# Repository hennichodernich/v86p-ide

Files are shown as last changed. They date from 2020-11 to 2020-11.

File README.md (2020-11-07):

# V86P 8-Bit IDE Controller

This is a variant of the XT-IDE ISA controller by [Glitch Works](http://www.glitchwrks.com/xt-ide) for Victor V86P 8086 laptops and compatibles.

This board is intended to be used with a custom BIOS like the XT-IDE Universal BIOS.

This design is based on [rev 4 of the Glitch Works XT-IDE](https://github.com/glitchwrks/xt_ide/tree/rev_4) using the information obtained by [MattinX](https://knm.org.uk/blog/2017/05/v86p-expansion/).

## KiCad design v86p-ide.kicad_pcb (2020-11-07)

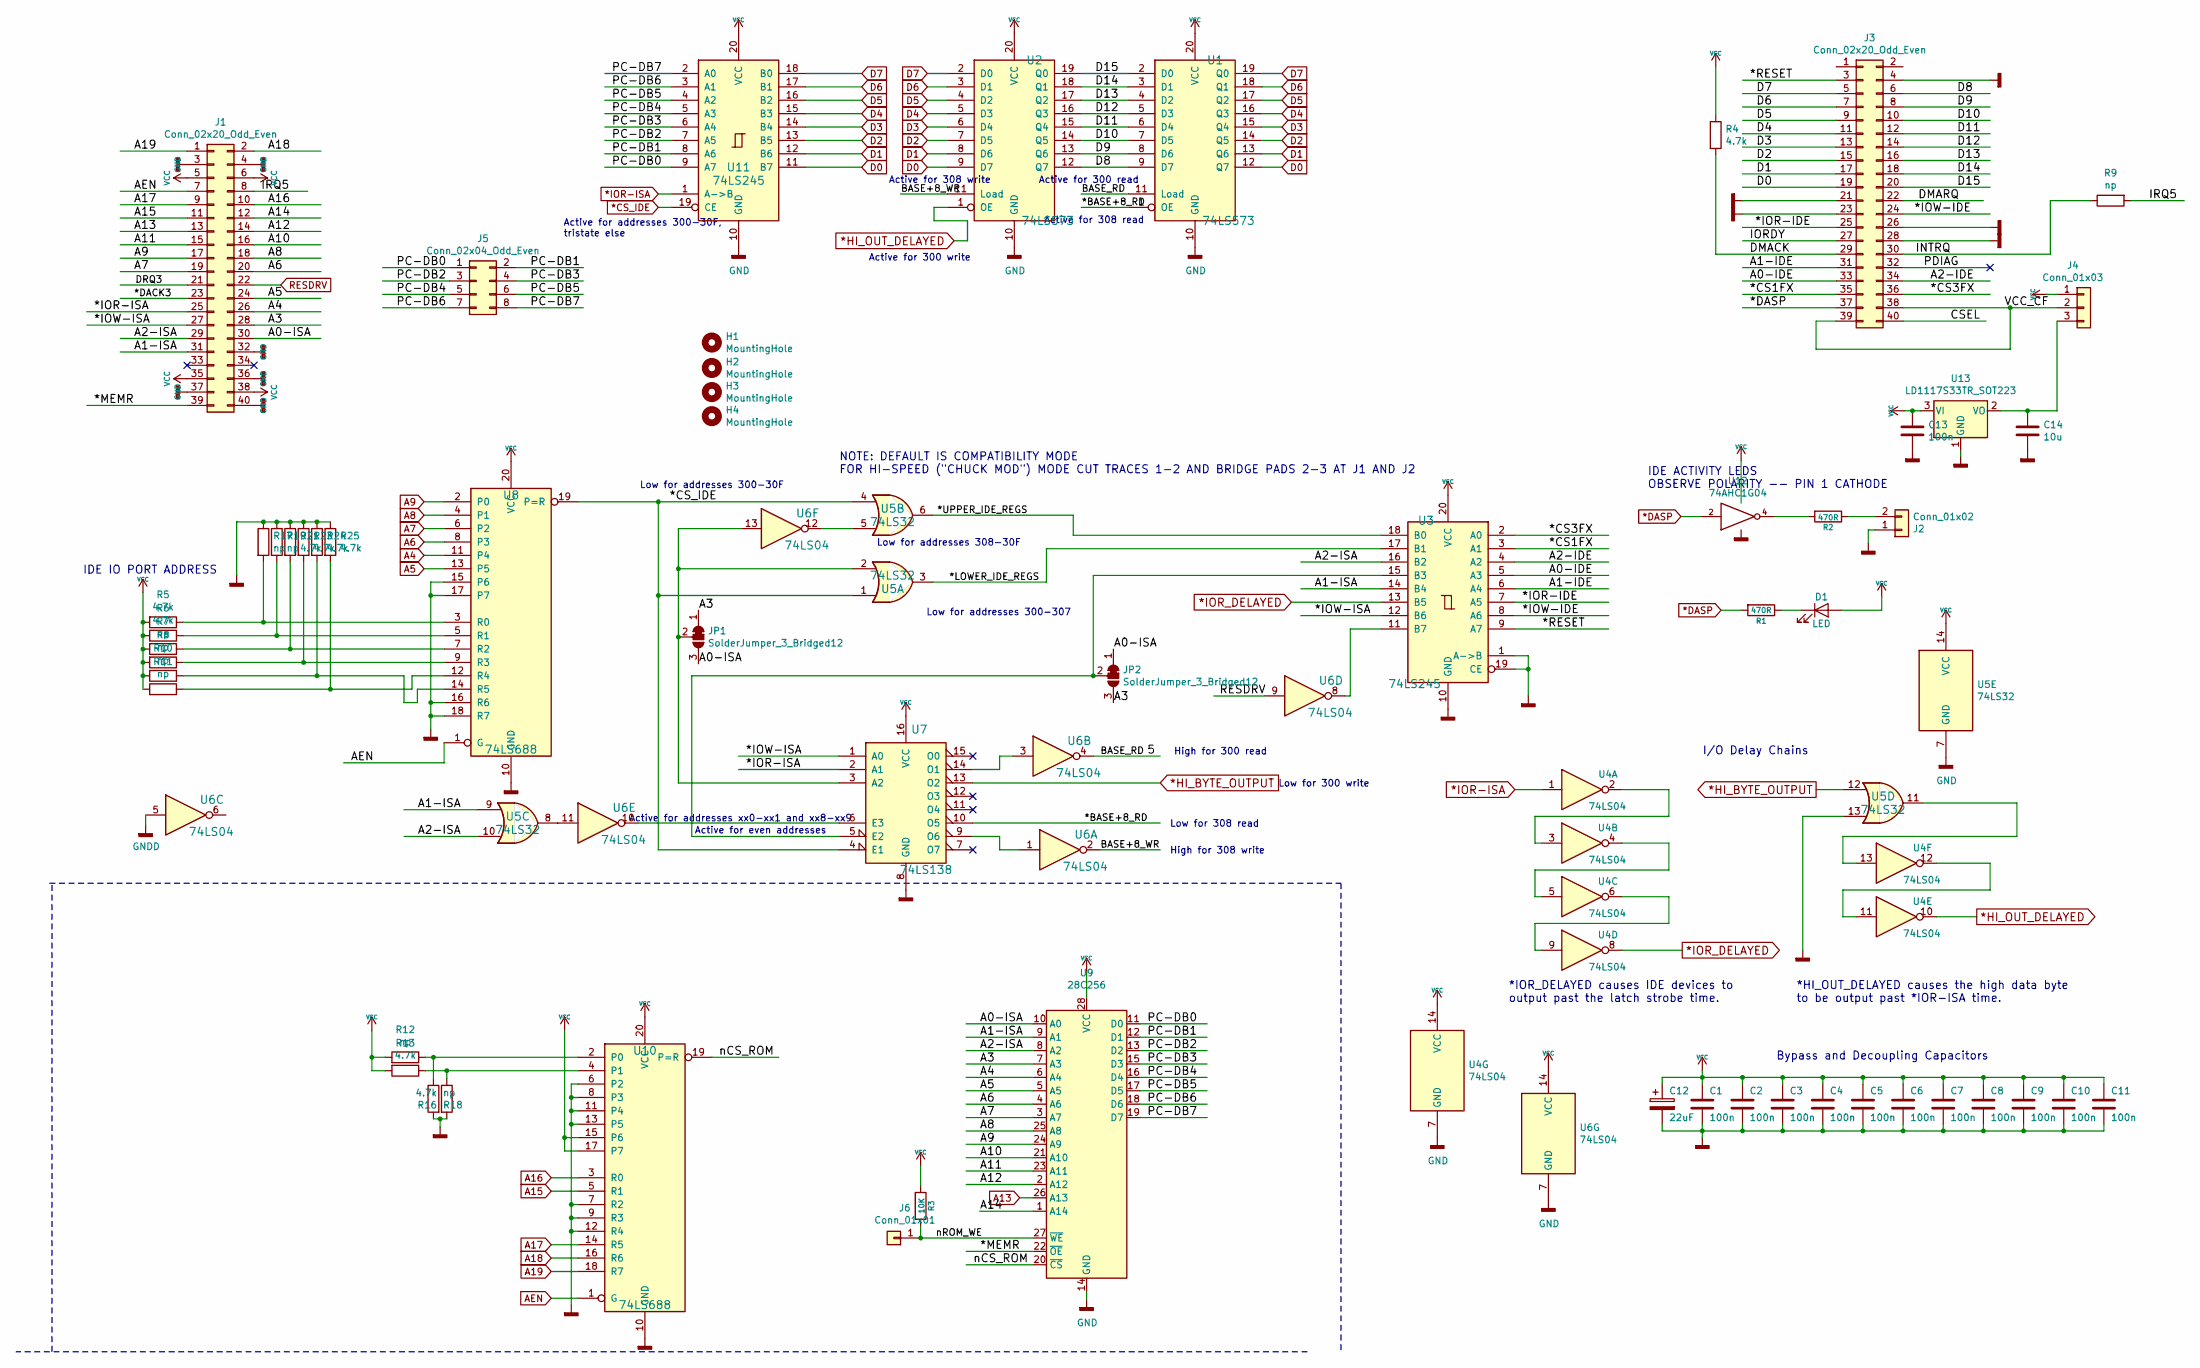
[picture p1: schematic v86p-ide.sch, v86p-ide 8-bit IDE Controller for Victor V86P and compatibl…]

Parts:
C1, C2, C3, C4, C5, C6, C7, C8, C9, C10, C11: 100n; C_0402_1005Metric
C12: 22uF; C_1206_3216Metric
C13: 100n; C_0603_1608Metric
C14: 10u; C_1206_3216Metric
D1: LED; LED_0603_1608Metric
H1, H2, H3, H4: MountingHole; MountingHole_3.2mm_M3_ISO7380
J1: Conn_02x20_Odd_Even; PinSocket_2x20_P2.54mm_Vertical
J2: Conn_01x02; PinHeader_1x02_P2.54mm_Horizontal
J3: Conn_02x20_Odd_Even; TE_4-1734839-0_1x40-1MP_P0.5mm_Horizontal
J4: Conn_01x03; PinHeader_1x03_P2.54mm_Horizontal
J5: Conn_02x04_Odd_Even; PinSocket_2x04_P2.54mm_Vertical
J6: Conn_01x01; PinHeader_1x01_P2.54mm_Horizontal
JP1, JP2: SolderJumper_3_Bridged12; SolderJumper-3_P1.3mm_Bridged12_RoundedPad1.0x1.5mm
R1, R2: 470R; R_0603_1608Metric
R3: 10K; R_0603_1608Metric
R4, R5, R6, R13, R16, R21, R23, R24, R25: 4.7k; R_0603_1608Metric
R7, R8, R9, R10, R11, R12, R17, R18, R19: np; R_0603_1608Metric
U1, U2: 74LS573; SOIC-20W_7.5x12.8mm_P1.27mm
U3, U11: 74LS245; SOIC-20W_7.5x12.8mm_P1.27mm
U4, U6: 74LS04; SOIC-14_3.9x8.7mm_P1.27mm
U5: 74LS32; SOIC-14_3.9x8.7mm_P1.27mm
U7: 74LS138; SOIC-16_3.9x9.9mm_P1.27mm
U8, U10: 74LS688; SOIC-20W_7.5x12.8mm_P1.27mm
U9: 28C256; DIP-28_W15.24mm_Socket
U12: 74AHC1G04; SOT-23-5
U13: LD1117S33TR_SOT223; SOT-223-3_TabPin2

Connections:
*CS_IDE: U5.1, U5.4, U7.4 (E1), U8.19 (P=R), U11.19 (CE)
*DASP: J3.37, R1.2, U12.2
*HI_BYTE_OUTPUT: U5.12, U7.13 (O2)
*HI_OUT_DELAYED: U2.1 (OE), U4.10
*IOR-ISA: J1.25, U4.1, U7.2 (A1), U11.1 (A->B)
*IOR_DELAYED: U3.13 (B5), U4.8
+5V: C1.1, C2.1, C3.1, C4.1, C5.1, C6.1, C7.1, C8.1, C9.1, C10.1, C11.1, C12.1, C13.1, D1.2 (A), J1.5, J1.6, J1.35, J1.38, J4.1, R3.1, R4.1, R5.2, R6.2, R7.2, R8.2, R10.2, R11.2, R12.2, R13.2, U1.20 (VCC), U2.20 (VCC), U3.20 (VCC), U4.14 (VCC), U5.14 (VCC), U6.14 (VCC), U7.16 (VCC), U8.20 (VCC), U9.28 (VCC), U10.15 (P6), U10.17 (P7), U10.20 (VCC), U11.20 (VCC), U12.3 (GND), U13.3 (VI)
/5: U1.11 (Load), U6.4
/*BASE+8_RD: U1.1 (OE), U7.10 (O5)
/*CS1FX: J3.35, U3.3 (A1)
/*CS3FX: J3.36, U3.2 (A0)
/*DACK3: J1.23
/*IOR-IDE: J3.25, U3.7 (A5)
/*IOW-IDE: J3.24, U3.8 (A6)
/*IOW-ISA: J1.27, U3.12 (B6), U7.1 (A0)
/*LOWER_IDE_REGS: U3.17 (B1), U5.3
/*MEMR: J1.39, U9.22 (~OE)
/*RESET: J3.3, U3.9 (A7)
/*UPPER_IDE_REGS: U3.18 (B0), U5.6
/A0-IDE: J3.33, U3.5 (A3)
/A0-ISA: J1.30, JP1.3 (B), JP2.1 (A), U9.10 (A0)
/A1-IDE: J3.31, U3.6 (A4)
/A1-ISA: J1.31, U3.14 (B4), U5.9, U9.9 (A1)
/A2-IDE: J3.34, U3.4 (A2)
/A2-ISA: J1.29, U3.16 (B2), U5.10, U9.8 (A2)
/A3: J1.28, JP1.1 (A), JP2.3 (B), U9.7 (A3)
/A10: J1.16, U9.21 (A10)
/A11: J1.15, U9.23 (A11)
/A12: J1.14, U9.2 (A12)
/A14: J1.12, U9.1 (A14)
/BASE+8_WR: U2.11 (Load), U6.2
/CSEL: J3.40
/D8: J3.6, U1.9 (D7), U2.12 (Q7)
/D9: J3.8, U1.8 (D6), U2.13 (Q6)
/D10: J3.10, U1.7 (D5), U2.14 (Q5)
/D11: J3.12, U1.6 (D4), U2.15 (Q4)
/D12: J3.14, U1.5 (D3), U2.16 (Q3)
/D13: J3.16, U1.4 (D2), U2.17 (Q2)
/D14: J3.18, U1.3 (D1), U2.18 (Q1)
/D15: J3.20, U1.2 (D0), U2.19 (Q0)
/DMACK: J3.29, R4.2
/DMARQ: J3.22
/DRQ3: J1.21
/INTRQ: J3.30, R9.1
/IORDY: J3.27
/IRQ5: J1.8, R9.2
/PC-DB0: J5.1, U9.11 (D0), U11.9 (A7)
/PC-DB1: J5.2, U9.12 (D1), U11.8 (A6)
/PC-DB2: J5.3, U9.13 (D2), U11.7 (A5)
/PC-DB3: J5.4, U9.15 (D3), U11.6 (A4)
/PC-DB4: J5.5, U9.16 (D4), U11.5 (A3)
/PC-DB5: J5.6, U9.17 (D5), U11.4 (A2)
/PC-DB6: J5.7, U9.18 (D6), U11.3 (A1)
/PC-DB7: J5.8, U9.19 (D7), U11.2 (A0)
/PDIAG: J3.32
/VCC_CF: J3.38, J3.39, J4.2
/nCS_ROM: U9.20 (~CS), U10.19 (P=R)
/nROM_WE: J6.1, R3.2, U9.27 (~WE)
A4: J1.26, U8.11 (P4), U9.6 (A4)
A5: J1.24, U8.13 (P5), U9.5 (A5)
A6: J1.20, U8.8 (P3), U9.4 (A6)
A7: J1.19, U8.6 (P2), U9.3 (A7)
A8: J1.18, U8.4 (P1), U9.25 (A8)
A9: J1.17, U8.2 (P0), U9.24 (A9)
A13: J1.13, U9.26 (A13)
A15: J1.11, U10.5 (R1)
A16: J1.10, U10.3 (R0)
A17: J1.9, U10.14 (R5)
A18: J1.2, U10.16 (R6)
A19: J1.1, U10.18 (R7)
AEN: J1.7, U8.1 (G), U10.1 (G)
D0: J3.19, U1.12 (Q7), U2.9 (D7), U11.11 (B7)
D1: J3.17, U1.13 (Q6), U2.8 (D6), U11.12 (B6)
D2: J3.15, U1.14 (Q5), U2.7 (D5), U11.13 (B5)
D3: J3.13, U1.15 (Q4), U2.6 (D4), U11.14 (B4)
D4: J3.11, U1.16 (Q3), U2.5 (D3), U11.15 (B3)
D5: J3.9, U1.17 (Q2), U2.4 (D2), U11.16 (B2)
D6: J3.7, U1.18 (Q1), U2.3 (D1), U11.17 (B1)
D7: J3.5, U1.19 (Q0), U2.2 (D0), U11.18 (B0)
unnamed: C14.1, J4.3, U13.2 (VO)
unnamed: D1.1 (K), R1.1
unnamed: J2.2, R2.1
unnamed: JP1.2 (C), U5.2, U6.13, U7.3 (A2)
unnamed: JP2.2 (C), U3.15 (B3), U7.5 (E2)
unnamed: R2.2, U12.4
unnamed: R10.1, R24.2, U8.14 (R5)
unnamed: R11.1, R25.2, U8.12 (R4)
unnamed: R12.1, R18.1, U10.2 (P0)
unnamed: R13.1, R16.1, U10.4 (P1)
unnamed: R5.1, R17.2, U8.3 (R0)
unnamed: R6.1, R19.2, U8.5 (R1)
unnamed: R7.1, R21.2, U8.7 (R2)
unnamed: R8.1, R23.2, U8.9 (R3)
unnamed: U3.11 (B7), U6.8
unnamed: U4.2, U4.3
unnamed: U4.4, U4.5
unnamed: U4.6, U4.9
unnamed: U4.11, U4.12
unnamed: U4.13, U5.11
unnamed: U5.5, U6.12
unnamed: U5.8, U6.11
unnamed: U6.1, U7.9 (O6)
unnamed: U6.3, U7.14 (O1)
unnamed: U6.10, U7.6 (E3)
RESDRV: J1.22, U6.9

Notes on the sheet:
IDE ACTIVITY LEDS OBSERVE POLARITY -- PIN 1 CATHODE
IDE IO PORT ADDRESS
NOTE: DEFAULT IS COMPATIBILITY MODE FOR HI-SPEED ("CHUCK MOD") MODE CUT TRACES 1-2 AND BRIDGE PADS 2-3 AT J1 AND J2
Bypass and Decoupling Capacitors
I/O Delay Chains
*IOR_DELAYED causes IDE devices to output past the latch strobe time.
*HI_OUT_DELAYED causes the high data byte to be output past *IOR-ISA time.
Low for addresses 300-30F
Low for addresses 300-307
Low for addresses 308-30F
Active for addresses xx0-xx1 and xx8-xx9
Active for even addresses
High for 300 read
Low for 300 write
Low for 308 read
High for 308 write
Active for 300 read
Active for 308 read
Active for 308 write
Active for 300 write
Active for addresses 300-30F, tristate else

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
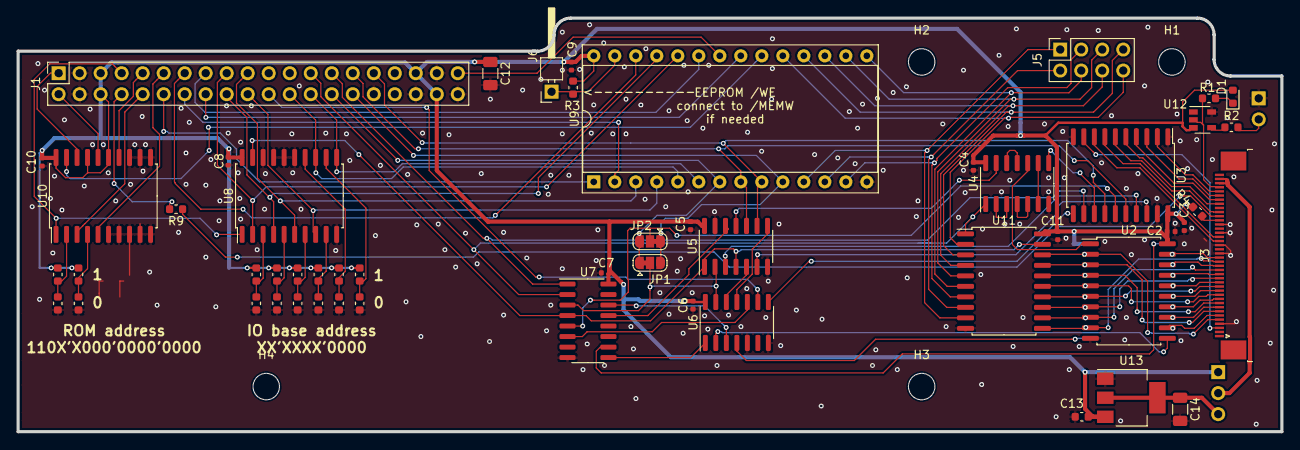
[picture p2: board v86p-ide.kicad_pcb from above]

Board: 2 copper layers, 152.8 x 50.0 mm, 61 parts (0 on the bottom side), 100 nets.

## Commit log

2020-11-07 First public release.
    [v86p-ide.kicad_pcb, v86p-ide.sch]
2020-11-07 Fixed DRC errors
    [v86p-ide.kicad_pcb]

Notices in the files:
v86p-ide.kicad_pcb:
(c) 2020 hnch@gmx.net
